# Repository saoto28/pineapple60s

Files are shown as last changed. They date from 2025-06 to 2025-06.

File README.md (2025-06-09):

# pineapple60s
Custom keyboard for ThinkPad X13 Gen2
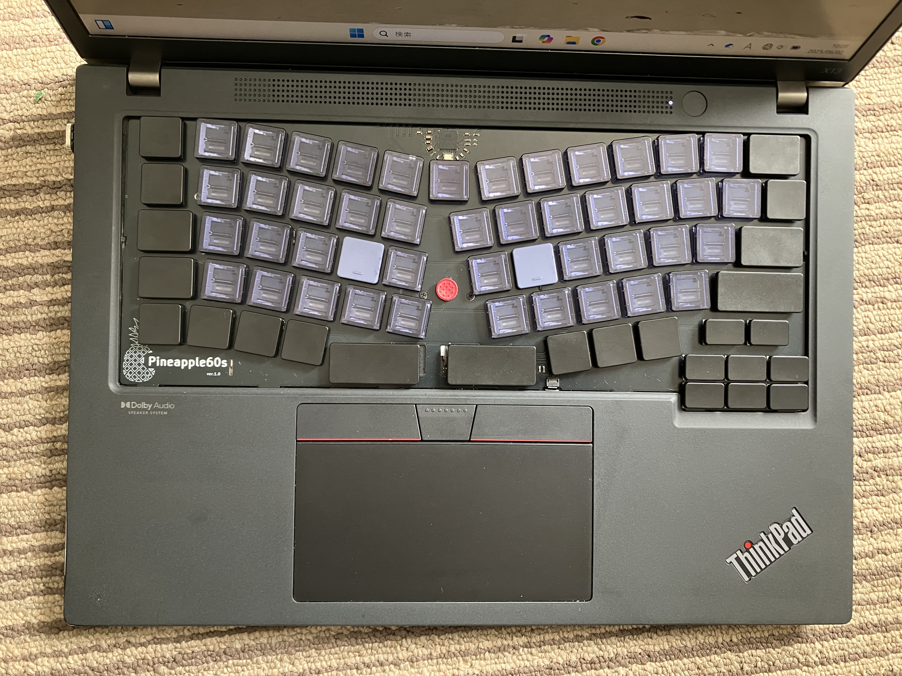
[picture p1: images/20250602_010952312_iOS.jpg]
Pineapple60s


## folder

### [/KiCAD8][1]
[1]:/KiCAD8

- PCB CAD files

### [/qmk_firmware][2]
[2]:/qmk_firmware/keyboards/pineapple/p60s

- keyboard configuration of qmk_firware 

Full qmk_firmware repository is here.
https://github.com/saoto28/qmk_firmware/tree/pineapple

## How to modify ThinkPad X13 Gen2 (Japanese)
https://note.com/saoto28/n/n716b7ca2e1f9

## links
All Pineapple projects repository:
https://github.com/saoto28/pineapple60

Twitter: https://x.com/saoto28

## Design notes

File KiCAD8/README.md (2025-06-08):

# Pineapple60s PCB design
## prerequisite
CAD: KiCAD 8

## history
### pineapple60s1_1_plane.* : remove key layouts from ver.1.1
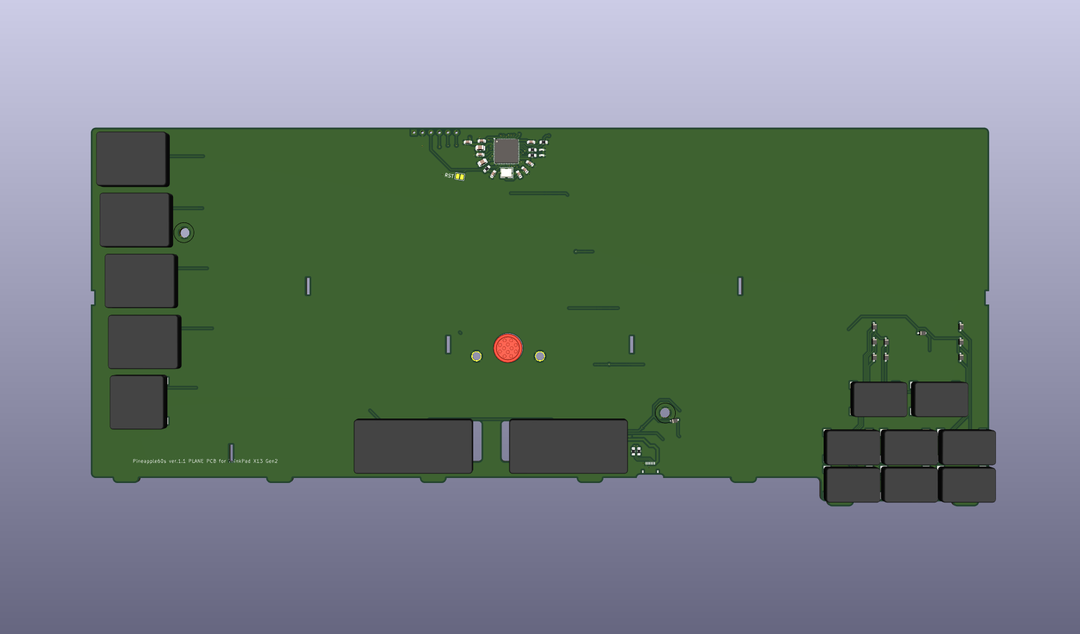
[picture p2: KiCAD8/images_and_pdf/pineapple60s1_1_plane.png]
pineapple60s ver.1.1 Plane PCB


### (pineapple60s1_1.* : ver.1.1, fixed some manual corrections made when installing ver. 1.0 at 2025-06)

### pineapple60s1_0a.* : same as ver 1.0, but, changed library folder location at 2025-06
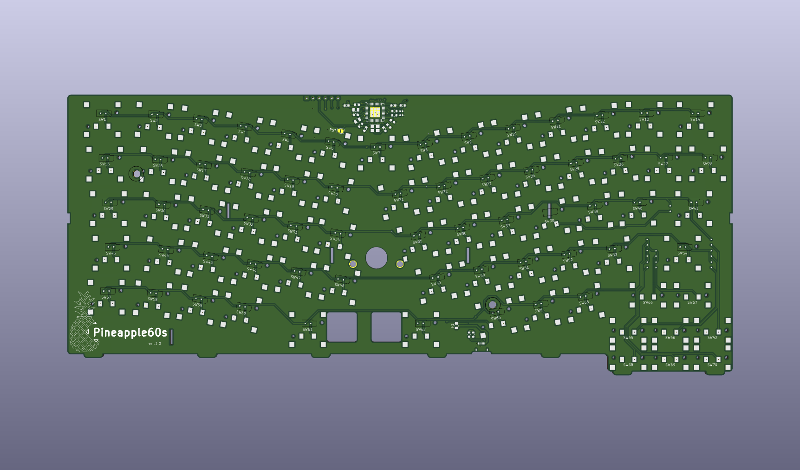
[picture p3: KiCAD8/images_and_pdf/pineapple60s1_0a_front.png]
pineapple60s ver.1.0a PCB front

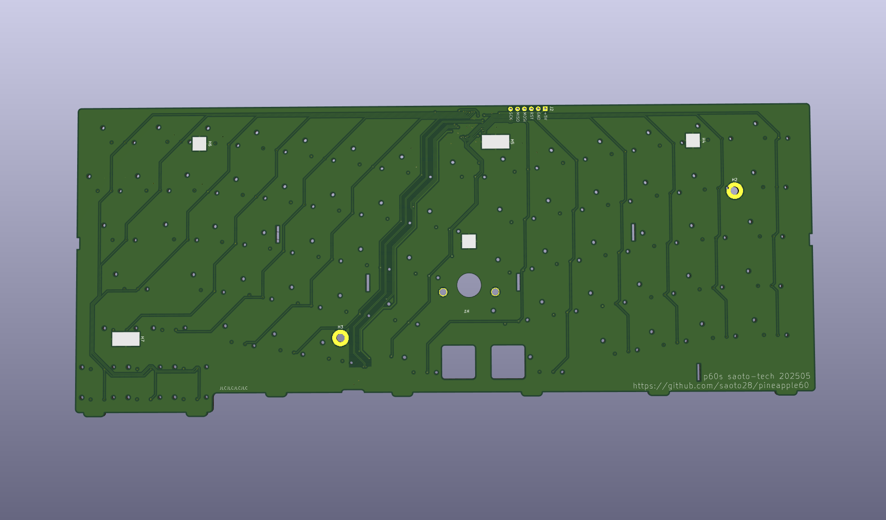
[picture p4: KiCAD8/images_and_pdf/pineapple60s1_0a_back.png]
pineapple60s ver.1.0a PCB back


[pineapple60s ver.1.0a schematic](images_and_pdf/pineapple60s1_0a_sch.pdf)

### (pineapple60s1_0.* : pineapple60s ver.1.0 first produced at 2025-05)

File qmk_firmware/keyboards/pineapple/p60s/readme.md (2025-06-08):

# pineapple60s

pineapple60s

*A short description of the keyboard/project*

* Keyboard Maintainer: [saoto28](https://github.com/saoto28)
* Hardware Supported: *The PCBs, controllers supported*
* Hardware Availability: *Links to where you can find this hardware*

Make example for this keyboard (after setting up your build environment):

    make pineapple60s:default

Flashing example for this keyboard:

    make pineapple60s:default:flash

See the [build environment setup](https://docs.qmk.fm/#/getting_started_build_tools) and the [make instructions](https://docs.qmk.fm/#/getting_started_make_guide) for more information. Brand new to QMK? Start with our [Complete Newbs Guide](https://docs.qmk.fm/#/newbs).

## Bootloader

Enter the bootloader in 3 ways:

* **Bootmagic reset**: Hold down the key at (0,0) in the matrix (usually the top left key or Escape) and plug in the keyboard
* **Physical reset button**: Briefly press the button on the back of the PCB - some may have pads you must short instead
* **Keycode in layout**: Press the key mapped to `QK_BOOT` if it is available

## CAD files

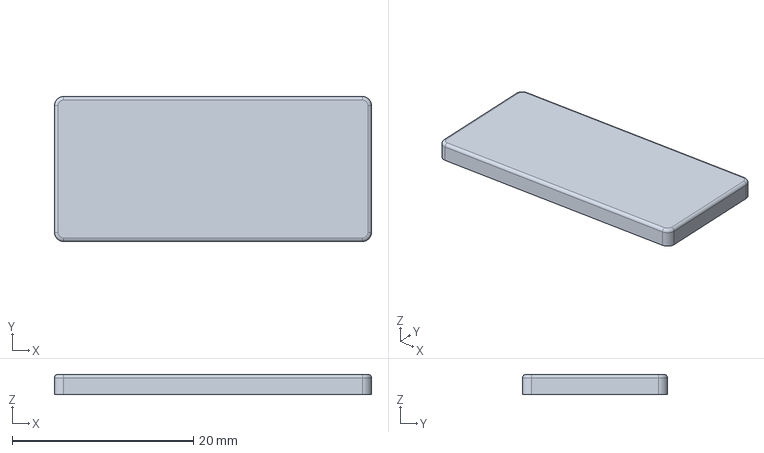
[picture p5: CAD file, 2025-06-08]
KiCAD8/3dcad/cap2U.step
35.0 x 16.0 x 2.25 mm

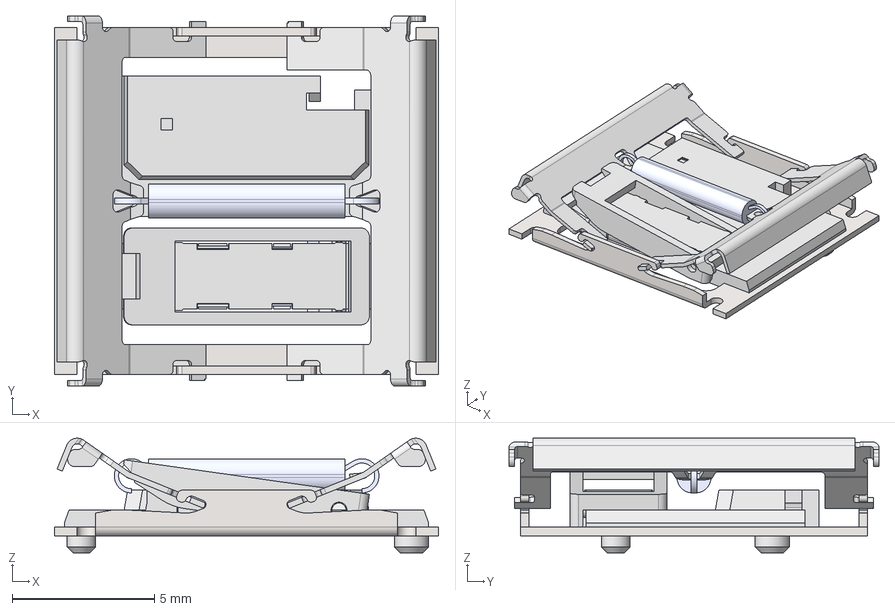
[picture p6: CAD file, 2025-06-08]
KiCAD8/3dcad/PG1316S_1U.step
13.5 x 13.0 x 4.03 mm
PG1316S-»ù×ù
Çý¶¯¸Ë
Æ½ºâ¼Ü
À»É
PG1316S-¶¯½Ó´¥Æ¬-´ ø´¥µã
PG1316S-¾²Æ¬-´ø´¥µ ã
Æ½ºâ¼Ü-B
1316S-»ù×ù¿¨¼þ

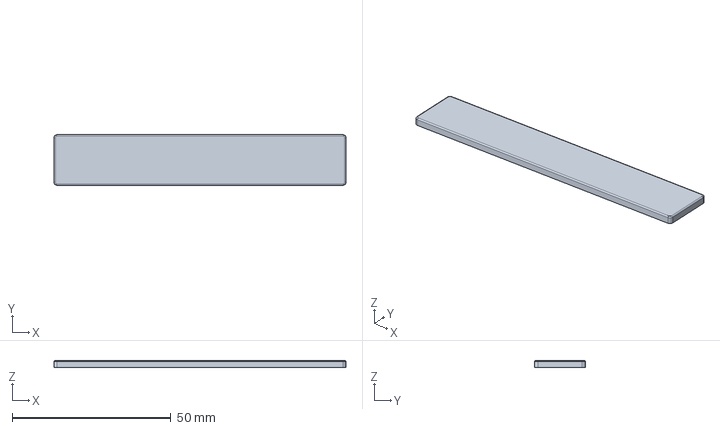
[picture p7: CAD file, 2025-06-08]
KiCAD8/3dcad/cap5U v2.step
92.0 x 16.0 x 2.25 mm

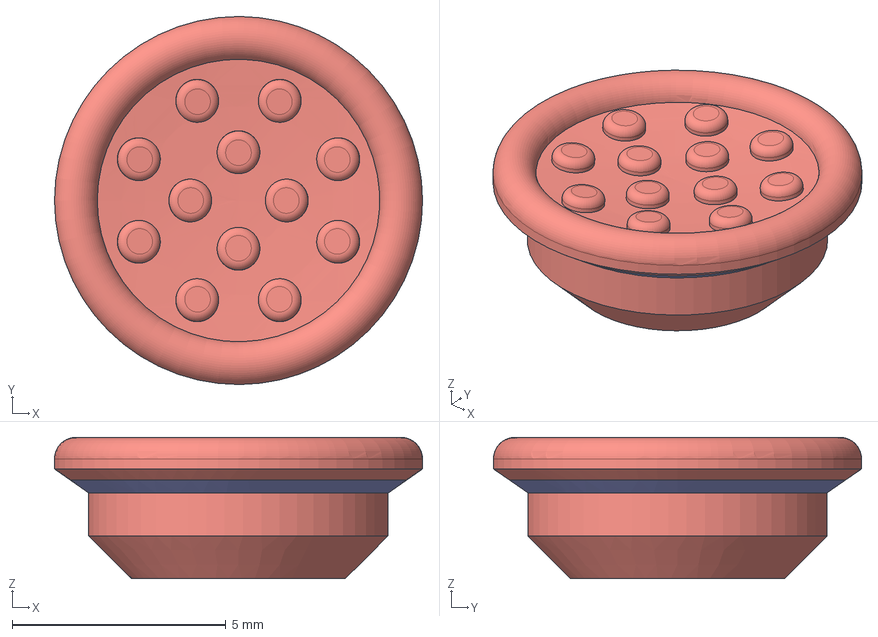
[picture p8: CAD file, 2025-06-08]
KiCAD8/3dcad/SuperLowSoftRim17S v2.step
8.60 x 8.60 x 3.30 mm

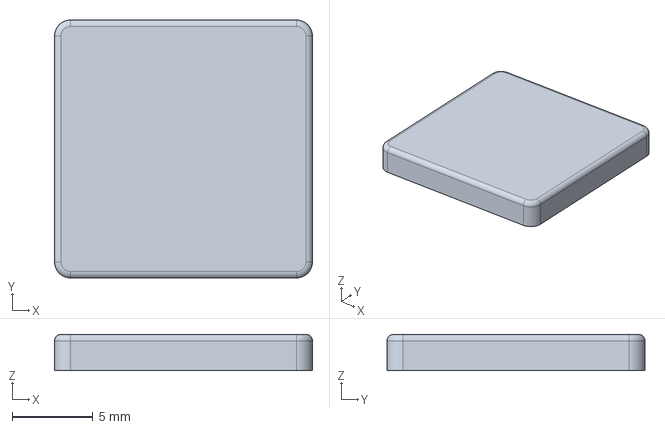
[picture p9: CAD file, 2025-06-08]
KiCAD8/3dcad/cap1U.step
16.0 x 16.0 x 2.25 mm

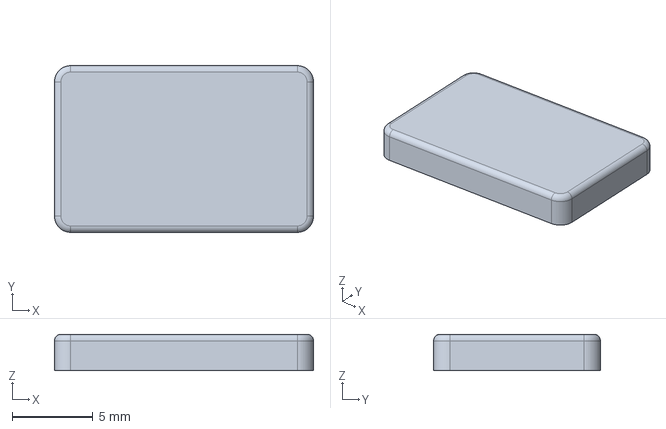
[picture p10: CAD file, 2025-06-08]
KiCAD8/3dcad/cap0.5U.step
16.0 x 10.3 x 2.25 mm

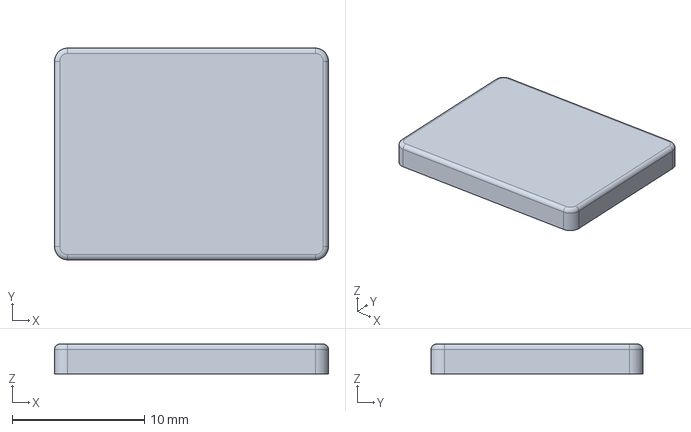
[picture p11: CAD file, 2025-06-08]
KiCAD8/3dcad/cap1.25U.step
20.7 x 16.0 x 2.25 mm

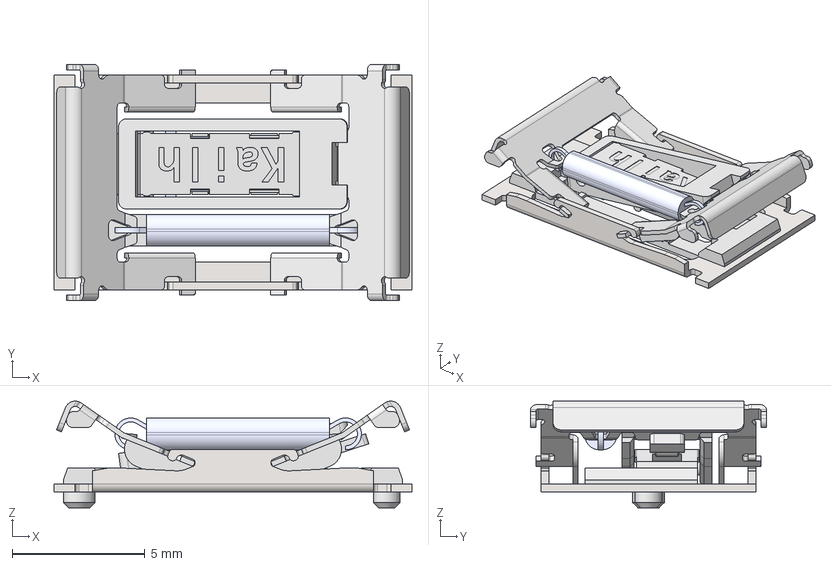
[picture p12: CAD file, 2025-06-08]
KiCAD8/3dcad/PG1316M_0.5U.step
13.5 x 8.90 x 4.03 mm
PG1316S-»ù×ù
Çý¶¯¸Ë
Æ½ºâ¼Ü-B¼þ
À»É
PG1316S-¶¯½Ó´¥Æ¬-´ ø´¥µã
PG1316S-¾²Æ¬-´ø´¥µ ã
Æ½ºâ¼Ü
1316S-»ù×ù¿¨¼þ

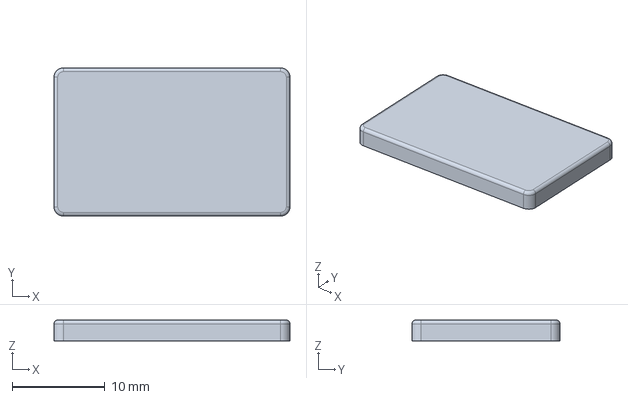
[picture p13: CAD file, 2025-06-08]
KiCAD8/3dcad/cap1.5U.step
25.5 x 16.0 x 2.25 mm

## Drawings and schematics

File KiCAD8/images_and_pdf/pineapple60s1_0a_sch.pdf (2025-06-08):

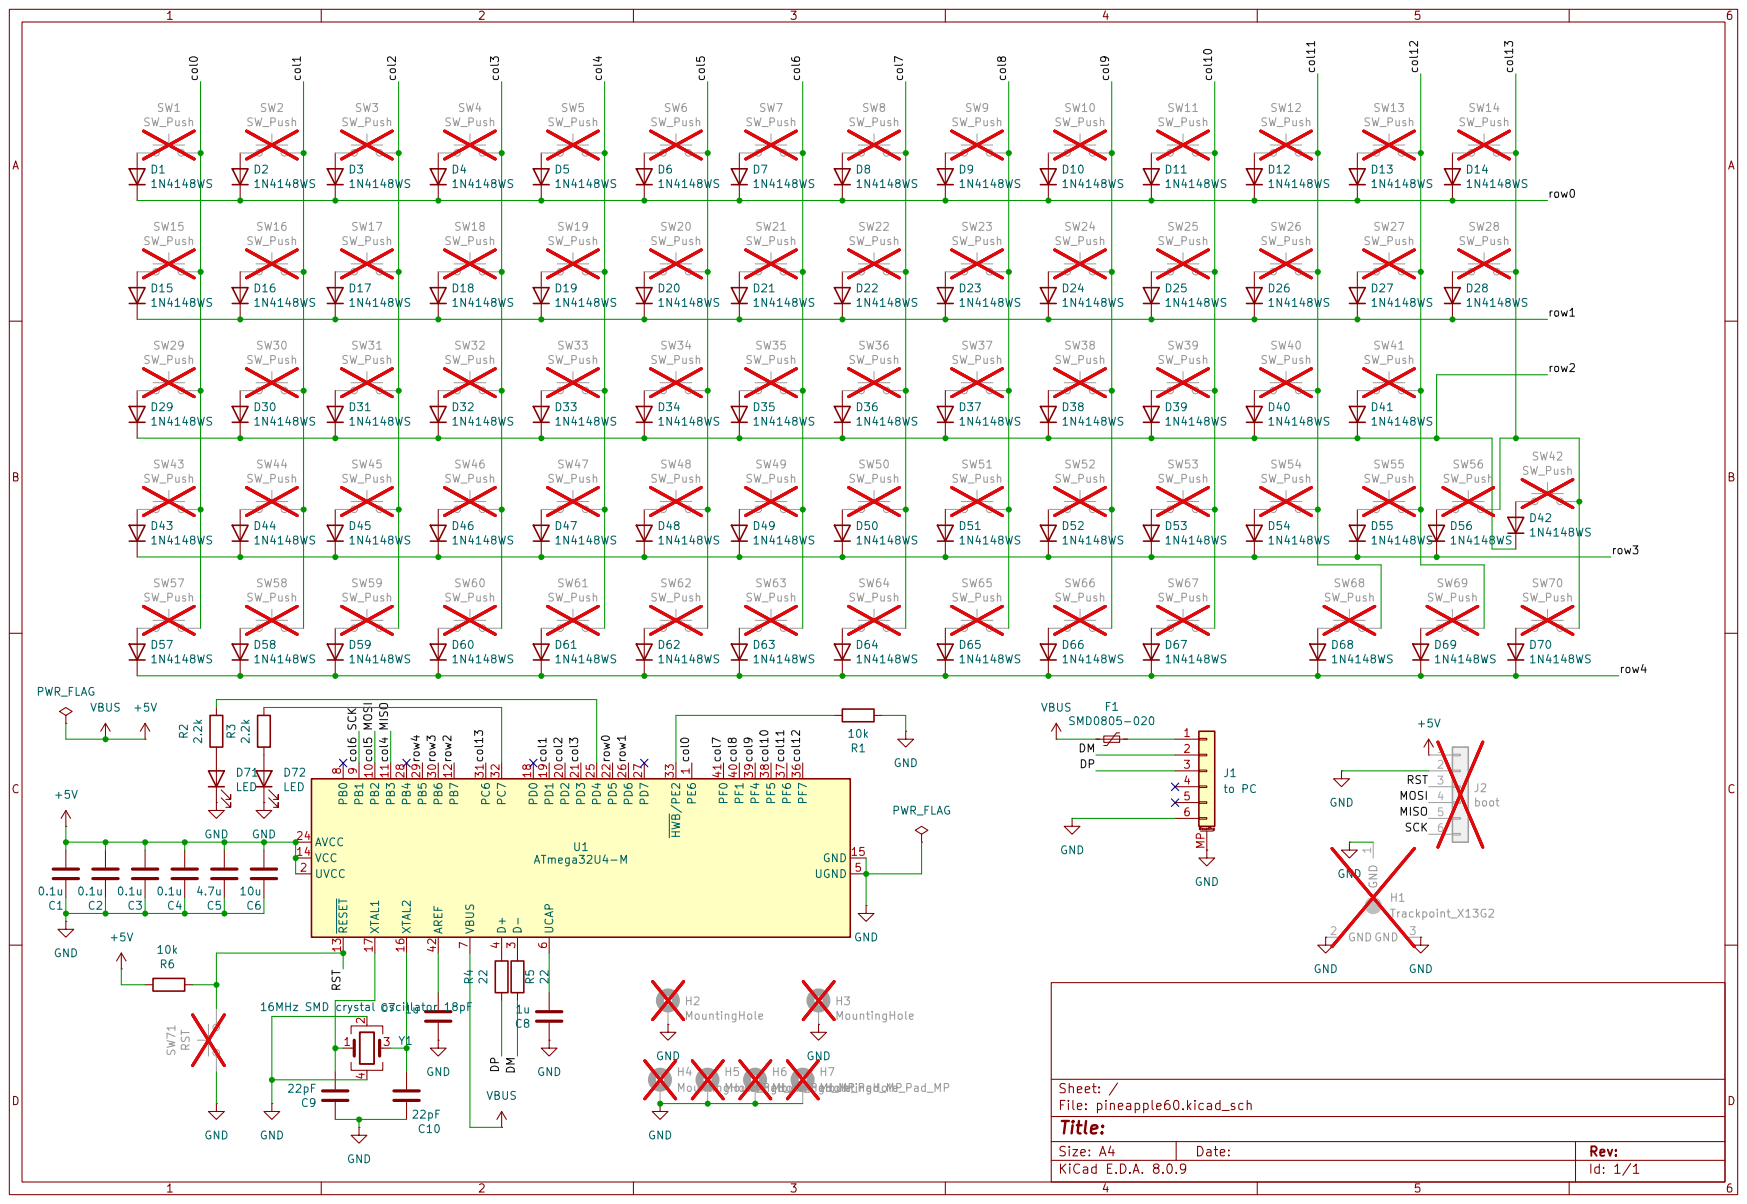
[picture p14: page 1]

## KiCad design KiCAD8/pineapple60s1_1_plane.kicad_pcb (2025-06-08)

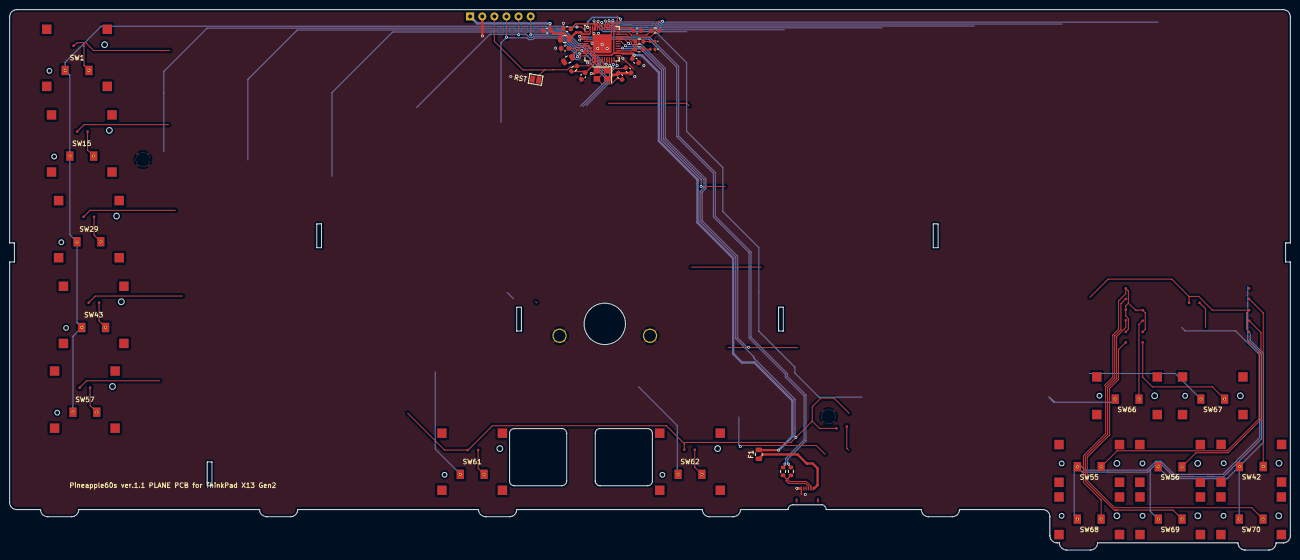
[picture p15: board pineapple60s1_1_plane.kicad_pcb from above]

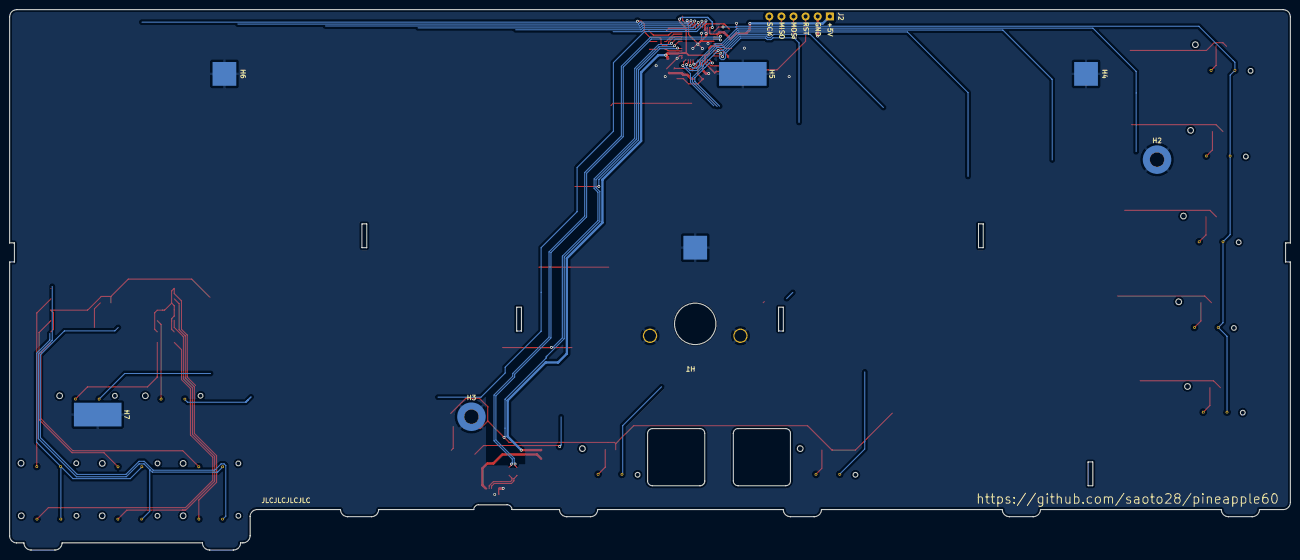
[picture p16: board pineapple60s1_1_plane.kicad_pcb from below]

Board: 2 copper layers, 269.0 x 113.5 mm, 63 parts (7 on the bottom side), 46 nets.

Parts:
C1, C2, C3, C4: 0.1u; C_0603_1608Metric
C5: 4.7u; C_0805_2012Metric
C6: 10u; C_0805_2012Metric
C7, C8: 1u; C_0603_1608Metric
C9, C10: 22pF; C_0603_1608Metric
D1, D15, D29, D42, D43, D54, D55, D56, D57, D61, D62, D63, D66, D67, D68, D69, D70: 1N4148WS; D_SOD-323F_mod
D71, D72: LED; LED_0402_1005Metric
F1: SMD0805-020; Fuse_0805_2012Metric
H1: Trackpoint_X13G2
H2, H3: MountingHole; MountingHole_3mm_Pad_Top_noVia
H4, H6: MountingHole_Pad_MP; SolderWirePad_1x01_SMD_5x5mm
H5, H7: MountingHole_Pad_MP; SolderWirePad_1x01_SMD_5x10mm
J1: to PC; HRS_FH34SRJ-6S-0.5SH_50_mod
J2: boot; PinHeader_0.8x06_P2.54mm_Vertical_noline_toponly
R1, R6: 10k; R_0603_1608Metric
R2, R3: 2.2k; R_0603_1608Metric
R4, R5: 22; R_0603_1608Metric
SW1, SW15, SW29, SW43: SW_Push; CPG1316S01D02_1.25U
SW42, SW55, SW56, SW66, SW67, SW68, SW69, SW70: SW_Push; CPG1316M01D02_0.5U
SW57: SW_Push; CPG1316S01D02_1U
SW61, SW62: SW_Push; CPG1316S01D02_2U
SW71: RST; SolderJumper-2_P1.3mm_Open_Pad1.0x1.5mm
U1: ATmega32U4-M; QFN-44-1EP_7x7mm_P0.5mm_EP5.2x5.2mm
Y1: 16MHz SMD crystal oscillator 18pF; Crystal_SMD_3225-4Pin_3.2x2.5mm

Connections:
+5V: C1.2, C2.2, C3.2, C4.2, C5.2, C6.2, F1.2, J2.1, R6.2, U1.2 (UVCC), U1.7 (VBUS), U1.14 (VCC), U1.24 (AVCC), U1.34 (VCC), U1.44 (AVCC)
/DM: J1.2, R5.1
/DP: J1.3, R4.1
/MISO: J2.5, SW61.1, U1.11 (PB3)
/MOSI: J2.4, SW62.1, U1.10 (PB2)
/RST: J2.3, R6.1, SW71.1, U1.13 (~RESET)
/SCK: J2.6, U1.9 (PB1)
/col0: SW1.1, SW15.1, SW29.1, SW43.1, SW57.1, U1.1 (PE6)
/col9: SW66.1, U1.39 (PF4)
/col10: SW67.1, U1.38 (PF5)
/col11: SW68.1, U1.37 (PF6)
/col12: SW55.1, SW69.1, U1.36 (PF7)
/col13: SW42.1, SW56.1, SW70.1, U1.31 (PC6)
/row0: D1.1 (K), U1.22 (PD5)
/row1: D15.1 (K), U1.26 (PD6)
/row2: D29.1 (K), D42.1 (K), U1.12 (PB7)
/row3: D43.1 (K), D54.1 (K), D55.1 (K), D56.1 (K), U1.30 (PB6)
/row4: D57.1 (K), D61.1 (K), D62.1 (K), D63.1 (K), D66.1 (K), D67.1 (K), D68.1 (K), D69.1 (K), D70.1 (K), U1.29 (PB5)
GND: C1.1, C2.1, C3.1, C4.1, C5.1, C6.1, C7.1, C8.1, C9.1, C10.1, D71.1 (K), D72.1 (K), H1.1 (GND), H1.2 (GND), H1.3 (GND), H2.1, H3.1, H4.1, H5.1, H6.1, H7.1, J1.6, J2.2, R1.1, SW71.2, U1.5 (UGND), U1.15 (GND), U1.23 (GND), U1.35 (GND), U1.43 (GND), U1.45 (GND), Y1.2, Y1.4
unnamed: D1.2 (A), SW1.2
unnamed: D15.2 (A), SW15.2
unnamed: D29.2 (A), SW29.2
unnamed: D42.2 (A), SW42.2
unnamed: D43.2 (A), SW43.2
unnamed: D55.2 (A), SW55.2
unnamed: D56.2 (A), SW56.2
unnamed: D57.2 (A), SW57.2
unnamed: D61.2 (A), SW61.2
unnamed: D62.2 (A), SW62.2
unnamed: D66.2 (A), SW66.2
unnamed: D67.2 (A), SW67.2
unnamed: D68.2 (A), SW68.2
unnamed: D69.2 (A), SW69.2
unnamed: D70.2 (A), SW70.2
unnamed: D71.2 (A), R2.1
unnamed: D72.2 (A), R3.1
unnamed: F1.1, J1.1
unnamed: C7.2, U1.42 (AREF)
unnamed: R4.2, U1.4 (D+)
unnamed: R5.2, U1.3 (D-)
unnamed: R3.2, U1.32 (PC7)
unnamed: R2.2, U1.25 (PD4)
unnamed: C8.2, U1.6 (UCAP)
unnamed: C9.2, U1.17 (XTAL1), Y1.1
unnamed: C10.2, U1.16 (XTAL2), Y1.3
unnamed: R1.2, U1.33 (~HWB/PE2)

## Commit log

2025-06-08 add kicad_sch
    [pineapple60s1_1_plane.kicad_sch]
2025-06-08 del pineapple60.kicad_sch
    [pineapple60.kicad_sch]
